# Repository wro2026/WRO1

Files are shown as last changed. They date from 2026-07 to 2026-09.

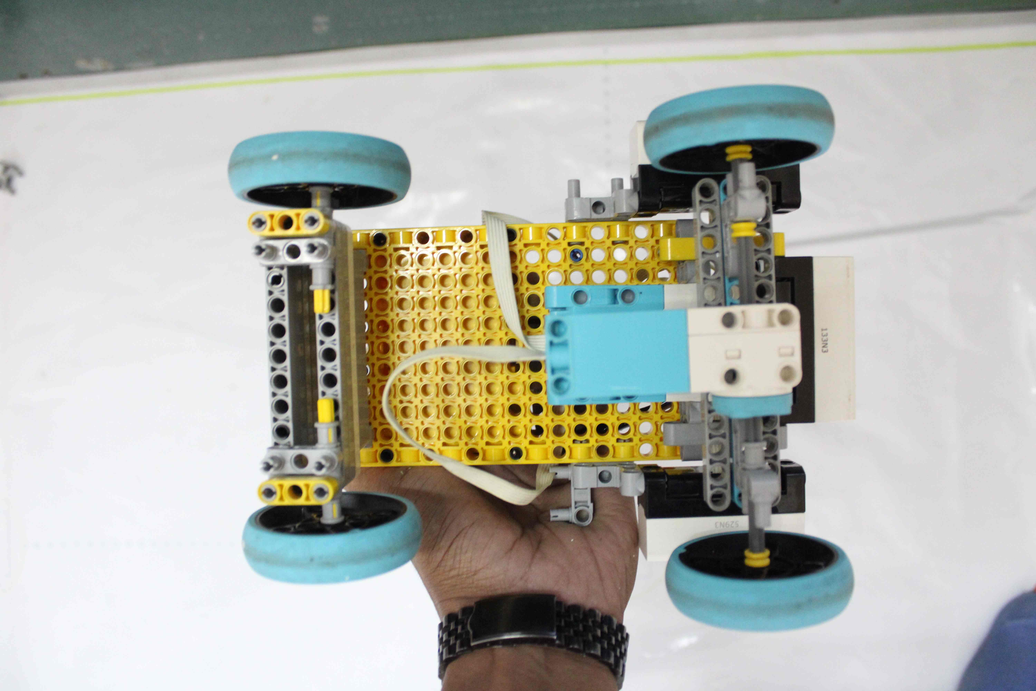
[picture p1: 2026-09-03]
Mechanical Design/Pictures/Pixabc.com_Compressed_to_500kb_IMG_7020.jpg

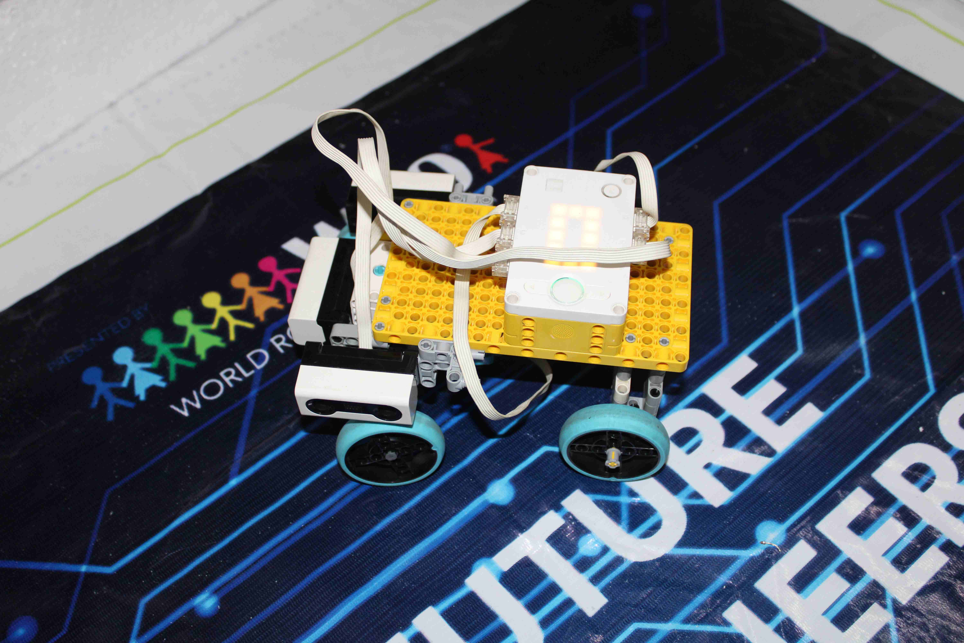
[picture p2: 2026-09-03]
Electronics/Pictures/Pixabc.com_Compressed_to_500kb_IMG_7013.jpg

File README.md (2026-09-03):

# WRO 2026 Future Engineers

This project is our WRO Future Engineers robot, developed with the goal of completing the competition challenge efficiently, reliably, and with as few accidents as possible. Our main target is to complete three laps within three minutes while maintaining accurate movement and avoiding unnecessary collisions. The robot has been developed through testing and several changes to both the hardware and software. The final version uses a LEGO SPIKE Prime Hub as the main controller, LEGO components for the mechanical structure, SPIKE Prime motors and sensors, a HuskyLens camera, and an ESP32 with a servo to allow the HuskyLens to communicate information to the SPIKE Prime system.

The robot has a LEGO-based chassis with approximate dimensions of 23 × 11 × 27 cm. The chassis is designed with a hollow structure to reduce unnecessary weight. LEGO was selected as the main construction material because it is easy to use, lightweight, stable, and simple to modify during development. This was particularly useful because the robot had to be changed and tested several times while we worked on improving its movement and turning performance. The LEGO structure also allowed us to make adjustments without having to rebuild the entire robot from the beginning.

The robot uses four wheels in total. The wheels have an approximate diameter of two inches, or about 5.08 cm. The SPIKE Prime Hub is positioned around the middle of the robot. This central placement helps keep the main controller within the body of the robot rather than placing it far toward one side. The drive system uses one small SPIKE Prime motor to drive the front two wheels. The drive system uses direct drive without gears. The steering system uses one large SPIKE Prime motor. The front two wheels are connected by a LEGO axle or bar, and the large motor rotates this bar so that the front wheels change direction. This provides the steering movement required by the robot.

The mechanical design was developed with simplicity in mind. Instead of using a complicated gear system, the drive motor is connected directly to the drive mechanism. This makes the system easier to understand and modify. The steering mechanism was also built using LEGO components so that the front wheels could be turned together. One of the main mechanical challenges during development was turning. Getting the robot to turn in a useful and repeatable way required testing and adjustment. The current version turns fairly well compared with the earlier versions, although turning was one of the main areas that required attention during development.

The chassis has remained stable during testing. We did not observe major problems with the structure bending, becoming loose, or coming apart during normal operation. We also did not identify a major tipping or leaning problem during our testing. These characteristics were important because the robot needs to remain stable while moving and turning. A stable structure makes it easier for the sensors to remain in their intended positions and allows the robot to behave more consistently during runs.

One of the most important decisions in the development of the robot was changing the platform used to control it. Our first version was built around a Raspberry Pi 4. This version was difficult and time-consuming to develop because we had to spend a lot of time working on the system and getting it to behave as required. Pairing and communication were also difficult during this stage. Because of these problems, we decided to change to the SPIKE Prime system. The second major version of the robot was therefore built using LEGO and SPIKE Prime. This change made the system easier for us to use and allowed us to make progress much more quickly. The move from the Raspberry Pi 4 version to the SPIKE Prime version was one of the biggest improvements made during the project.

The electronics system is controlled mainly by the LEGO SPIKE Prime Hub. The robot uses distance sensors, a SPIKE Prime color sensor, and a HuskyLens camera. There are distance sensors positioned around the robot, including one at the front and sensors on the sides. The front distance sensor is used to detect the environment in front of the robot, while the side distance sensors provide information about the robot's surroundings. These sensors are important for detecting distances and helping the robot make movement decisions.

The HuskyLens is mounted at the front of the robot and faces forward. It is used to detect colors. The color information is important because the robot uses it as part of its decision-making process. We originally used the SPIKE Prime color sensor by itself, but later added the HuskyLens because we found it to be more accurate for the color detection that we needed. This was an improvement to the sensing system because it gave us another way to identify the required color information.

The HuskyLens cannot directly communicate all of its information to the SPIKE Prime Hub in the way required by our system. To solve this problem, we use an ESP32 and a servo as an interface between the HuskyLens and the SPIKE Prime color sensor. The system works through the chain of HuskyLens to ESP32 to servo to SPIKE Prime color sensor and then to the SPIKE Prime Hub. The HuskyLens detects the color, the ESP32 processes the relevant information, and the servo is used to communicate the color change to the SPIKE Prime color sensor. The SPIKE Prime system can then use the color sensor information as part of its control process.

The SPIKE Prime Hub is powered using its rechargeable battery. The motors and sensors are connected to the SPIKE Prime Hub using the LEGO connection system. We did not make custom power wiring for the robot, and the main system does not use a separate external power supply. This keeps the electronics relatively simple and makes the system easier to assemble and modify.

We have not measured exact electrical values such as current consumption, total power consumption, or other detailed electrical measurements. These values are therefore not included as measured specifications of the robot. If we perform these measurements later, they can be added to the documentation. For the current version, the important point is that the robot uses the SPIKE Prime rechargeable battery as its main power source and the SPIKE Prime Hub as its main controller.

The software for the robot is written in Python. The program controls the motors, reads information from the sensors, and controls the robot's movement. The basic behavior is that the robot drives forward, detects when it needs to turn, performs the turn, and continues moving. The program also counts turns. After twelve turns, the robot is programmed to continue for approximately 30 cm and then stop. This provides a defined stopping behavior for the current program.

The robot normally drives at a fixed speed during normal movement. When it approaches a turn, the speed is reduced to help with the turning process. The steering system uses a fixed turning angle. The exact numerical value of the steering angle has not been measured and is therefore not listed as a specific number in this documentation. The turning behavior was adjusted through testing so that the robot could turn more effectively.

The distance sensors are used to detect distances around the robot. The front distance sensor helps detect what is ahead, while the side sensors provide additional information about the environment. The HuskyLens and SPIKE Prime color sensor provide color information that is used together with the distance information when the robot makes decisions. The robot therefore does not depend on only one sensor for its complete behavior. Instead, information from the available sensors is used to determine what action should be taken.

The general decision process used by the robot is based on detecting a situation, checking the available color information, deciding whether the robot should turn right or left, and then steering the robot. In a simplified form, the process can be described as detecting the situation, checking the color, deciding on the direction, and steering. The exact numerical sensor thresholds used by the final program have not been recorded in this documentation, so they are not stated as specific values.

When an unexpected sensor reading occurs, the program can retry the detection rather than immediately continuing with an incorrect decision. This gives the robot another opportunity to receive a usable sensor reading. This behavior is useful because sensor readings can sometimes not provide the expected information on the first attempt.

The algorithm was selected because it is straightforward and easier for us to program and understand. Our main priority was to create a system that could reliably complete the course rather than making the software unnecessarily complicated. The algorithm was developed through testing and tuning. During development, we tested different detection lengths for the distance sensors and changed values such as sensor thresholds, motor speed, and the steering angle. These changes were made based on how the robot behaved during testing.

Testing was an important part of the development process. Rather than assuming that the first design would work correctly, we tested the robot and used the results to make changes. Turning was one of the main areas that required testing because the robot needed to change direction accurately while maintaining its position and avoiding accidents. The distance sensor detection behavior was also tested by trying different detection lengths. Motor speed and steering settings were adjusted to find behavior that worked better on the course.

The project has gone through two major versions. The first version was developed using a Raspberry Pi 4. This version was difficult to develop because of the amount of work required to make the system behave correctly and because pairing was difficult. The second version moved to LEGO and SPIKE Prime. This change made development easier and allowed us to make progress more quickly. The switch to LEGO and SPIKE Prime was therefore one of the most significant changes made during the project.

The current robot combines a simple LEGO mechanical structure with a SPIKE Prime control system and additional sensing through HuskyLens and ESP32. The mechanical design focuses on keeping the robot lightweight, stable, and easy to modify. The electronics focus on using the SPIKE Prime Hub, distance sensors, the SPIKE color sensor, and the HuskyLens to provide the information needed for the robot's movement decisions. The software connects these components together and controls the robot according to the programmed behavior.

The project is designed around the goal of completing three laps within three minutes while minimizing accidents. Speed is therefore important, but reliability is also important. A robot that moves quickly but frequently makes incorrect turns or has accidents would not meet the project's goal as effectively as a robot that maintains a good balance between movement speed and accuracy. For this reason, testing and tuning focused on the interaction between sensor detection, motor speed, and turning behavior.

There are some specifications that have not yet been measured. We have not recorded an exact top speed, exact motor torque, exact steering angle, exact total robot weight, or detailed electrical power consumption. These values should not be treated as known specifications. If more detailed measurements are taken in future testing, they can be added to the repository to make the technical documentation more complete.

The current design has several strengths. The LEGO chassis is lightweight and easy to modify. The structure has remained stable during testing without major bending or loosening problems. The SPIKE Prime Hub provides a simpler development platform than the Raspberry Pi 4 system that we originally tried. The combination of distance sensors, the SPIKE Prime color sensor, and HuskyLens provides multiple sources of information for the robot. The software is also straightforward, making it easier to understand, test, and adjust.

At the same time, turning remains an important area of the robot's development. Although the current robot turns fairly well, turning was one of the biggest mechanical and programming challenges during development. Further testing could be used to improve the consistency of turns and to determine more accurate mechanical measurements such as the steering angle. Additional testing could also provide measured speed, weight, power consumption, and other useful technical information.

The development process demonstrates an iterative approach. We began with one hardware and control approach, identified problems, and then changed the system. We tested the new system, adjusted sensor and motor settings, and continued improving the robot. Instead of treating the original design as final, we used the results from testing to guide changes. This process helped us move from the Raspberry Pi 4 version to the SPIKE Prime version and improve the robot's overall usability.

The final system is intended to be understandable and reproducible from the information provided in this repository. The mechanical design, electronics, software, algorithms, testing, iterations, photos, and videos can be organized in separate folders so that each part of the project can be documented clearly. The documentation focuses on the actual robot and its development rather than including unnecessary material that does not contribute to understanding the project.

Overall, this project represents the development of a WRO Future Engineers robot from an initial Raspberry Pi 4 concept to a LEGO SPIKE Prime-based system. The robot uses a lightweight LEGO chassis, four wheels, a small drive motor, a large steering motor, distance sensors, a SPIKE Prime color sensor, a HuskyLens camera, an ESP32, and a servo interface. Its software is written in Python and uses sensor information to control movement, turning, and stopping behavior. Through testing and iteration, the robot was adjusted to improve its turning, sensor detection, motor behavior, and overall reliability.

The main lesson from the development process was the importance of testing and making changes based on actual robot behavior. The switch from Raspberry Pi 4 to SPIKE Prime significantly improved the development process for our team, while the addition of HuskyLens improved the color detection system. The current design provides a practical balance between mechanical simplicity, electronic functionality, and software control. The project will continue to be improved through further testing, especially in areas such as turning consistency and measured performance.

Our final objective remains to complete three laps within three minutes with the least number of accidents possible. Every part of the robot, from the lightweight LEGO chassis to the sensor system and Python program, contributes to this objective. The repository documents the development process and the current design so that the work completed by the team can be clearly understood and evaluated.

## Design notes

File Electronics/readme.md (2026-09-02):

2. Power & Sensor Architecture

2.1 System Architecture

The SPIKE Prime Hub is the main controller. It controls the drive and steering motors and processes information used for autonomous navigation. An ESP32 is also used as an interface because the SPIKE Prime system cannot directly interpret the HuskyLens camera.
The main information flow is:
Distance sensors → SPIKE Prime Hub → navigation decisions
HuskyLens → ESP32 → servo interface → SPIKE Prime color sensor → SPIKE Prime Hub
SPIKE Prime rechargeable battery → SPIKE Prime Hub → SPIKE Prime components

2.2 Power System

The robot is powered by the SPIKE Prime rechargeable battery. The SPIKE Prime motors and sensors use the Hub's normal connections. The ESP32 and servo form the additional HuskyLens interface.
The present documentation does not contain measured current values for each component, so unsupported current figures are not stated. For a complete final power budget, current should be measured for the drive motor, steering motor, Hub electronics, ESP32, servo and sensors under representative operating conditions.



2.3 Sensor Selection

The robot uses distance sensors, the SPIKE Prime color sensor and HuskyLens.
•	Distance sensors provide information about objects or walls around the robot.
•	The HuskyLens provides color information from the front of the robot.
•	The SPIKE Prime color sensor provides the input pathway through which the HuskyLens color information is communicated to the SPIKE system.
Initially, the robot relied on the SPIKE Prime color sensor. During development, the team found that HuskyLens gave more accurate color detection. Instead of abandoning SPIKE Prime, an ESP32 and servo interface was added. This preserved SPIKE Prime as the main controller while improving color detection.

2.4 Sensor Placement and Field Geometry

The distance sensors are positioned on the sides of the robot so that they can observe nearby walls or objects relative to the robot's lateral position. This information helps the robot determine when a navigation decision is required.
The HuskyLens is mounted at the front and faces forward because color information must be obtained from the area ahead of the robot. The SPIKE Prime color sensor is positioned so that the servo-operated interface can communicate the detected color change.
Placement is therefore linked to the geometry of the field: side sensors observe lateral boundaries, while the forward-facing camera observes information in the robot's path.

2.5 Calibration and Reliability

Sensor thresholds and detection distances are treated as adjustable parameters rather than permanent assumptions. During testing, different distance thresholds were tried to determine when the robot should respond to an object or field condition.
A practical calibration procedure is to collect repeated readings at known distances, identify a stable threshold that separates the required field condition from normal travel, and then repeat the test several times. The final threshold should be selected from the repeated test results.
For reliability, an unexpected or unstable sensor reading should not immediately trigger a turn. The software should repeat the detection/decision process and only continue when a valid condition is identified. This reduces the effect of a single noisy reading.

2.6 Electronics Design Change

The major electronics iteration was the addition of HuskyLens, ESP32 and servo. The original SPIKE color sensor was not sufficiently accurate for the team's color-detection requirement. HuskyLens improved detection, but it could not directly communicate with SPIKE Prime. The interface solved this compatibility constraint.
This demonstrates a subsystem trade-off: improving sensing accuracy increased electronics complexity. The team accepted the additional ESP32 and servo because the resulting detection system was more useful while SPIKE Prime could remain the main controller.

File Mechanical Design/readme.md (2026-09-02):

1. Mobility & Mechanical Design

1.1 Chassis Design

Our robot chassis is constructed entirely from LEGO components. The approximate overall dimensions are 23 cm × 11 cm × 27 cm. The chassis uses a hollow LEGO structure to reduce unnecessary mass while retaining the structural members needed to mount the motors, wheels, hub and sensors.
LEGO was selected because it allows rapid mechanical iteration. During development, parts can be repositioned without permanently modifying the structure. This was particularly important when we changed the steering geometry and sensor positions during testing.
The robot has four wheels with an approximate diameter of 2 inches (5.08 cm). The SPIKE Prime Hub is positioned approximately near the middle of the chassis. This keeps the main mass close to the center of the vehicle and provides a practical mounting arrangement for the drive and steering systems.

1.2 Drive System

The robot uses one SPIKE Prime small motor for propulsion. The motor is connected directly to the front two wheels without intermediate gearing. The front wheels are mechanically linked through an axle so that the drive motor transfers rotation to both wheels.
The direct-drive arrangement was selected because it has few mechanical parts, is easy to inspect, and is simple to modify. The robot can drive forwards and backwards.
The main trade-off is that direct drive provides less opportunity to change wheel speed or torque through gearing. We accepted this trade-off because the current competition objective prioritizes predictable movement and reliable turning over a complex drivetrain.

1.3 Steering System

One SPIKE Prime large motor controls steering. The two front wheels are connected by a LEGO steering bar. When the steering motor rotates the bar, both front wheels change direction together.
The steering motor is mechanically separate from the drive motor. Separating propulsion and steering makes the control system easier to tune because drive speed and steering angle can be adjusted independently.
Testing showed that the current steering arrangement can complete the required turns reliably. Steering performance was improved by adjusting the steering angle and reducing drive speed during turns.

1.4 Torque and Speed Reasoning

The drive-wheel diameter is approximately 5.08 cm, giving a wheel circumference of approximately 15.96 cm. The theoretical linear speed can therefore be estimated from wheel rotational speed using v = πdN/60, where d is wheel diameter in metres and N is wheel speed in revolutions per minute.
For example, once the actual motor output speed under load is measured, it can be converted directly into the robot's theoretical wheel speed. The measured ground speed should then be compared with the theoretical value because wheel slip, load and surface friction can reduce the actual speed.
Wheel torque is important because the robot must accelerate the chassis and overcome rolling resistance while turning. The effective tractive force can be related to wheel torque by F = T/r, where T is wheel torque and r is wheel radius. Because the exact loaded motor torque has not yet been measured, we do not claim an unsupported numerical torque value. Instead, the design uses direct drive and moderate speed to favor predictable motion.
For the final build, the recommended validation measurements are: time over a fixed 1 m distance, maximum repeatable speed, loaded wheel torque if measurement equipment is available, and turning radius. These measurements should be recorded on the final competition robot rather than estimated from unloaded motor specifications.

1.5 Mechanical Stability and Rigidity

The four-wheel configuration provides four contact points with the field. The hollow chassis reduces mass while retaining the LEGO members needed to support the motors, wheels and electronics.
During normal driving tests, the chassis remained assembled and no major bending or separation was observed. The steering assembly also remained mechanically connected while changing direction.
The main mechanical risks are loose LEGO connections, steering backlash, wheel slip and excessive speed during turns. These risks are reduced by checking connections before runs, using a consistent steering setting, slowing before turns, and testing the robot repeatedly on the competition surface.

1.6 Design Choices and Trade-offs

Decision	Alternative considered	Reason for final choice	Engineering trade-off
LEGO chassis	More permanent/custom chassis	Fast modification and iteration	Less rigid than some custom structures
SPIKE Prime drive	Raspberry Pi-based system	Simpler motor/control integration	Less software flexibility
Direct drive	Intermediate gearing	Fewer mechanical parts	Less ability to trade speed for torque
Separate steering motor	Single combined mechanism	Independent steering control	Requires an additional motor

A major system-level decision was changing from the original Raspberry Pi 4 approach to SPIKE Prime. The Raspberry Pi version was difficult and time-consuming because development included a learning-based system and pairing/setup problems. The SPIKE Prime version allowed the team to make mechanical and software changes more quickly. The final choice therefore prioritized reliable development and repeatable testing.

1.7 Design Iterations and Testing

Version 1: Raspberry Pi 4

The first version used a Raspberry Pi 4. The main difficulty was system complexity. Development of the learning approach required significant time, while pairing and setup also caused delays. The slow development cycle made mechanical iteration harder.

Version 2: LEGO SPIKE Prime

The second version changed to SPIKE Prime with a LEGO chassis. This reduced setup complexity and made mechanical changes faster. The current design uses four wheels, 2-inch wheels, one small drive motor, one large steering motor, direct drive and a LEGO steering bar.
Testing and tuning focused on steering angle, drive speed and detection behavior. The robot slows before turns because a lower speed reduces overshoot and makes the steering response more predictable.

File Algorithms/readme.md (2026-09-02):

4. Systems Thinking & Engineering Decisions

4.1 How the Subsystems Work Together

The robot is an integrated system rather than four independent parts. The mechanical system determines how quickly and accurately the robot can turn. The sensor architecture determines what information the software receives. The software converts sensor information into navigation decisions. Those decisions command the mechanical drive and steering system.
The main interaction chain is:
Field condition → sensors → ESP32/HuskyLens interface where required → SPIKE Hub → navigation decision → motor speed/steering → robot movement → new sensor readings
A change in one subsystem therefore affects the others. For example, increasing speed may improve straight-line travel time but can make turning less accurate. Similarly, moving a sensor changes the distance at which the software must react.

4.2 Engineering Constraints

•	The robot must operate autonomously.
•	The robot must complete 3 laps within the 3-minute objective.
•	The chassis must remain mechanically stable during repeated driving.
•	Steering must be controllable independently from propulsion.
•	Sensor information must be available in time for a turn decision.
•	HuskyLens must be integrated despite the SPIKE Prime compatibility limitation.
•	The design must remain practical to build and modify with the available LEGO system.

4.3 Major Engineering Decisions

Problem	Options	Decision	Reasoning
Main control platform	Raspberry Pi 4 or SPIKE Prime	SPIKE Prime	Reduced setup complexity and allowed faster development
Color detection	SPIKE color sensor only or HuskyLens	HuskyLens + ESP32 + servo interface	Improved color detection while retaining SPIKE as main controller
Drive transmission	Direct drive or gearing	Direct drive	Simple, compact and easy to modify
Steering	Single mechanical steering system or separate control	Separate large motor	Allows independent steering control
Navigation	Complex learning-based approach or simpler sensor logic	Sensor-based logic	Easier to test, tune and understand for the current task

4.4 Iteration Cycle

The development process followed an iterative engineering cycle:
Build → Test → Identify limitation → Change design → Retest → Select the better-performing configuration
Iteration 1 changed the main platform from Raspberry Pi 4 to SPIKE Prime because the first approach was too complex and slow to develop.
Iteration 2 changed the color-detection architecture by adding HuskyLens, ESP32 and a servo because the original color-sensing approach was less accurate.
Further tuning changed detection distances, motor speed and steering angle based on observed robot behavior.

4.5 Risk and Failure Analysis

Risk / failure point	Possible effect	Mitigation	Validation
Incorrect distance reading	Turn triggered too early/late	Use calibrated thresholds and repeat unstable detections	Repeated sensor tests
Color detection error	Wrong left/right decision	Use HuskyLens and validate color information	Repeated color tests
High speed during turn	Overshoot or missed path	Slow before turning	Compare turn behavior at different speeds
Steering backlash	Inconsistent turn angle	Use a fixed steering setting and check mechanical connections	Repeated turning tests
Wheel slip	Actual path differs from expected path	Use controlled speed and observe wheel/field interaction	Repeated distance/turn tests
Loose chassis connection	Mechanical instability	Inspect and reinforce critical LEGO connections	Repeated driving tests
Interface failure	HuskyLens information unavailable to SPIKE	Keep SPIKE color sensor as the communication pathway and retry detection	Integration tests

4.6 Testing Metrics

To make engineering decisions measurable, the final testing record should use repeatable metrics rather than subjective descriptions alone.



4.7 Performance Objective

The algorithm's main objective is to complete 3 laps within 3 minutes while minimizing accidents. Therefore, the engineering goal is not simply maximum speed. The selected design balances speed, sensing reliability, steering control and mechanical stability.
The final configuration should be selected from repeated tests. If a higher speed reduces lap time but increases missed turns or accidents, the lower and more reliable speed is the better engineering choice for the competition objective.

4.8 Final Engineering Rationale

The final robot was developed by progressively reducing unnecessary complexity while improving the parts that directly affect autonomous performance. SPIKE Prime was selected as the main control platform because it accelerated development. Direct drive and LEGO construction were retained because they are simple and easy to modify. HuskyLens was added because improved color detection was valuable, while the ESP32 and servo interface solved the compatibility constraint.
The resulting architecture connects mechanical, electronic and software decisions: sensor placement determines when the software can detect a condition; detection thresholds determine when the robot begins a maneuver; motor speed and steering angle determine the physical result; and repeated testing is used to tune these parameters. This systems approach is intended to produce a robot that is not only functional, but also understandable, testable and reproducible.

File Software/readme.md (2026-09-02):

3. Software Architecture & Obstacle Strategy

3.1 Programming Architecture

The robot is programmed in Python. The software coordinates motor control, sensor input, steering and autonomous navigation.
The software can be understood as five functional stages: sensing, validation, decision, motion control and route completion.



3.2 Main Autonomous State Machine

The robot follows the following state sequence:

1.	START: initialize the controller, motors, sensors and required variables.

2.	DRIVE: move forward at the normal driving speed.

3.	DETECT: monitor the distance sensors for a navigation condition.

4.	VALIDATE: confirm the detection and check the relevant color information.

5.	DECIDE: determine whether the required direction is left or right.

6.	SLOW: reduce drive speed before the turn.

7.	TURN: move the steering motor to the selected steering angle.

8.	COUNT: increment the completed-turn counter.

9.	CONTINUE: return to forward driving.

10.	STOP: after 12 turns, drive approximately 30 cm and stop.

The state-machine structure was selected because it separates sensing, decision-making and movement. This makes the behavior easier to test and tune than a single long sequence of motor commands.

3.3 Turn Decision Algorithm

The decision process is:
Detect condition → Check color → Decide left/right → Steer → Continue
The robot does not use one fixed direction for every turn. Instead, the relevant sensor condition and color information are considered before the steering direction is selected.
Conceptually, the control logic is:
IF a turn condition is detected: validate the reading; check color; select LEFT or RIGHT; reduce speed; apply the steering angle; complete the turn; count the turn; return to driving.

3.4 Obstacle Strategy and Edge Cases

Distance sensors provide information about objects or walls. If an object is detected, the robot checks the color information before selecting a path. The selected direction is then passed to the steering system.
•	If the sensor reading is unexpected or unstable, repeat the detection/decision process rather than immediately making a turn.
•	If a valid condition is detected but the color information does not provide the expected classification, the software should repeat the sensing step before committing to a direction.
•	During turns, the robot reduces drive speed to reduce overshoot.
•	After each successful turn, the turn counter is updated so the route can be completed without a manual stop.

3.5 Steering Control

The large SPIKE Prime motor controls the front-wheel steering mechanism. A predetermined steering angle is used for turns. This angle was adjusted during testing to obtain reliable turning behavior.
The robot normally drives at a fixed speed and uses a lower speed during turns. This creates a simple two-speed strategy: efficient forward travel and controlled turning.

3.6 Turn Counting and Stopping

The current route-control sequence is designed to complete 12 turns. Once the counter reaches 12, the robot continues for approximately 30 cm and then stops.
This stopping strategy reduces dependence on a manual operator and gives the autonomous run a defined end condition.

3.7 Software Testing and Tuning

The main software parameters tuned during development were sensor thresholds, detection distance, motor speed and steering angle. These parameters were changed after observing robot behavior during testing.



The final report should retain the measured values from the team's actual tests. Values should not be invented merely to make the documentation appear complete.

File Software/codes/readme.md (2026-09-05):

# =============================================================================
# Pybricks (SPIKE Prime / Inventor Hub)
# WRO Obstacle Challenge — NO parallel parking
# -----------------------------------------------------------------------------
# Merge of:
#   * WRO Open Challenge corridor driver (90 deg gyro arcs at openings)
#   * HuskyLens color dodges (GREEN = LEFT, RED = RIGHT)
#
# PORT MAP
#     A = drive motor (rear, with encoder)
#     B = steering motor (front wheels)
#     C = distance sensor LEFT
#     D = distance sensor FRONT
#     E = distance sensor RIGHT
#     F = HuskyLens UART, Color Recognition, 9600 baud
#
# Teach the HuskyLens:
#     Color ID 1 = GREEN pillar  -> pass on the LEFT
#     Color ID 2 = RED   pillar  -> pass on the RIGHT
#
# WHAT THE CAR DOES
#     CRUISE     wall-center + IMU heading hold, watch for openings AND colors
#     COLOR      GREEN: 35 deg LEFT while the pillar is visible, then hold
#                50 deg RIGHT for 30 cm, straighten the wheels, then go
#                20 cm straight. RED is the mirror: 35 deg RIGHT, then
#                50 deg LEFT for 30 cm, straighten, 20 cm straight.
#                Corridor heading is KEPT (gyro is not zeroed) so the next
#                90 deg corner still lines up. Wall-centering is boosted
#                briefly so the car returns to the middle of the lane.
#     APPROACH   opening seen; hold heading until the front wall is close
#     TURN       closed-loop 90 deg gyro arc (never stops mid-run)
#     POST       short gyro-straight, then back to CRUISE
#     FINAL      after MAX_TURNS (12 = 3 laps of 4 corners), center for
#                FINAL_DRIVE_MM and stop. No parking.
#
# The car is not allowed to stop until every 90 deg turn is done.
# A corner turn is ONLY started when a real opening is detected (the open
# side reads farther than OPEN_DISTANCE_MM = 1000 mm) AND the front wall
# has been reached. A front wall alone -- e.g. a color block that the
# HuskyLens has not identified yet -- NEVER triggers a turn; the car just
# slows down and lets the color dodge handle it.
#
# STARTUP
#     1. Point the car straight down the corridor.
#     2. Physically straighten the front wheels.
#     3. Press Run. That heading becomes 0.
# =============================================================================

from pybricks.hubs import PrimeHub
from pybricks.pupdevices import Motor, UltrasonicSensor
from pybricks.parameters import Port, Stop, Icon, Color
from pybricks.tools import wait, StopWatch
from pybricks.iodevices import UARTDevice

# ------------------------- PORTS -------------------------
hub = PrimeHub()
drive = Motor(Port.A)
steer = Motor(Port.B)
left_sensor = UltrasonicSensor(Port.C)
front_sensor = UltrasonicSensor(Port.D)
right_sensor = UltrasonicSensor(Port.E)

# --------------------- DRIVE SETTINGS -------------------
# Regulated rear-motor speed, deg/s. Negative if the car drives backward.
DRIVE_SPEED = -500
TURN_SPEED = -280           # slower in the 90 deg arc (same SIGN as DRIVE)
STEERING_SPEED = 400       # deg/s of the steering servo

# Steering MOTOR angle, not the road-wheel angle.
MAX_STEERING_DEG = 32
MAX_TURN_STEERING_DEG = 40          # also the hard clamp for dodges/recovery
# STEERING_SIGN: +1 if a POSITIVE motor angle turns the car LEFT
# (same meaning as the working SPIKE 3 program). Flip to -1 if reversed.
STEERING_SIGN = 1
# YAW_SIGN: used after converting Pybricks heading (clockwise +)
# into a left-positive yaw like the SPIKE 3 program. Flip if turns go
# the wrong way.
YAW_SIGN = 1

# ---------------------- STOP SETTINGS -------------------
# Front-wall stopping is ONLY used in FINAL, after all MAX_TURNS are done.
STOP_DISTANCE_MM = 180
FRONT_CONFIRMATIONS = 2
FRONT_STOP_MAX_YAW_DEG = 12
EMERGENCY_STOP_DISTANCE_MM = 10

# ------------------- CRUISE CONTROLLER GAINS ------------
WALL_KP = 0.11
WALL_DEADBAND_MM = 8
WALL_FILTER_AMOUNT = 0.25
HEADING_KP = 1.20
YAW_DAMPING = 1.80

# After a color dodge, wall-centering is stronger for this long so the
# car hunts the middle of the lane instead of staying offset.
RECENTER_MS = 3000
RECENTER_WALL_KP = 0.20
RECENTER_DEADBAND_MM = 4

# ------------------- TURN DETECTION ---------------------
SPIKE_JUMP_MM = 500
SPIKE_CONFIRMATIONS = 4
BASELINE_FILTER_AMOUNT = 0.12
MAX_WALL_DISTANCE_MM = 2000
# An opening ONLY counts when the open side reads FARTHER than this.
# The GREEN/RED color blocks stand INSIDE the corridor, so the side
# sensors never read > 1000 mm for them -- a block can never look like
# an opening, and a front wall without a real opening never triggers a
# turn (the HuskyLens color dodge handles blocks instead).
OPEN_DISTANCE_MM = 1000

# ------------------- TURN EXECUTION ---------------------
TURN_AT_FRONT_DISTANCE_MM = 900
FRONT_CLOSE_CONFIRMATIONS = 1
WALL_RETURN_CONFIRMATIONS = 2
WALL_RETURN_MARGIN_MM = 150     # side wall counts as "back" if within baseline + this
MAX_APPROACH_DISTANCE_MM = 700
POST_TURN_DRIVE_MM = 100
ODOMETER_MM_PER_MOTOR_DEG = 0.49    # ~56 mm wheel; pi*56/360

TURN_ANGLE_DEG = 90
TURN_KP = 2.0
TURN_DONE_TOLERANCE_DEG = 6
TURN_TIMEOUT_MS = 6000

MAX_TURNS = 12                      # 3 laps x 4 corners
FINAL_DRIVE_MM = 300                # settle between walls, then stop

# When something is straight ahead but NO opening was detected, never turn:
# it is almost certainly a color block the HuskyLens has not identified yet.
# Slow down so the camera has time to see the color, and the color dodge
# takes over from there.
BLOCK_AHEAD_SLOWDOWN_MM = 500
BLOCK_AHEAD_SPEED = -200

# ------------------- COLOR (HuskyLens) ------------------
#  GREEN  -> pass on the LEFT   (dodge LEFT, recover RIGHT)
#  RED    -> pass on the RIGHT  (dodge RIGHT, recover LEFT)
#  Logical steering convention here: + = wheels RIGHT, - = wheels LEFT.
GREEN_ID = 1                        # color ID of the GREEN pillar
RED_ID = 2                          # color ID of the RED pillar
GREEN_STEER = -35                   # -35 logical  = LEFT dodge
GREEN_RECOVER = 50                  # +50 logical  = RIGHT recovery
RED_STEER = 35                      # +35 logical  = RIGHT dodge
RED_RECOVER = -50                   # -50 logical  = LEFT recovery
COLOR_RECOVER_MM = 300              # 30 cm HOLDING the recovery angle
RECOVER_STRAIGHT_MM = 200           # 20 cm straight after straightening
COLOR_LOST_CONFIRM_MS = 300

HUSKY_PORT = Port.F
HUSKY_BAUD = 9600
HUSKY_POWER_PIN = 0                 # 2 if the camera needs hub pin power
HUSKY_TIMEOUT_MS = 60

LOOP_TIME_MS = 50
PRINT_DEBUG = False

# ------------------------ MODES -------------------------
MODE_CRUISE = 0
MODE_APPROACH = 1
MODE_TURN = 2
MODE_POST = 3
MODE_FINAL = 4
MODE_NAMES = ("CRUISE", "APPROACH", "TURN", "POST", "FINAL")

# ------------------------------------------------------------------ helpers
def clamp(value, low, high):
    if value < low:
        return low
    if value > high:
        return high
    return value

def distance_is_valid(value):
    return value is not None and value > 0

def read_mm(sensor):
    """Pybricks returns 2000 mm when nothing is seen; map that to -1."""
    try:
        d = sensor.distance()
    except OSError:
        return -1
    if d is None or d <= 0 or d >= 2000:
        return -1
    return d

def angle_difference(new_angle, old_angle):
    difference = new_angle - old_angle
    while difference > 180:
        difference -= 360
    while difference < -180:
        difference += 360
    return difference

def wrap_angle(angle):
    while angle > 180:
        angle -= 360
    while angle <= -180:
        angle += 360
    return angle

def yaw_left_positive():
    """
    Pybricks hub.imu.heading() is clockwise-positive (RIGHT).
    The Open Challenge controller is left-positive. Convert here so the
    rest of the math matches the working SPIKE 3 program.
    """
    return wrap_angle(YAW_SIGN * (-hub.imu.heading()))

def traveled_mm(start_position):
    return abs(drive.angle() - start_position) * ODOMETER_MM_PER_MOTOR_DEG

def update_side_reading(reading_mm, baseline, open_count, open_threshold_mm):
    """
    Wall tracking for one side. An 'open' count only builds up when the
    side truly opens up: the reading jumps away from the wall baseline AND
    is farther than open_threshold_mm (1000 mm). A missing reading means
    no wall within 2 m -- that is open too. Wall-like readings (a color
    block in the corridor) always stay below the threshold and never count.
    """
    if distance_is_valid(reading_mm):
        if baseline is None:
            if reading_mm <= MAX_WALL_DISTANCE_MM:
                baseline = reading_mm
            return baseline, 0
        if (
            reading_mm > baseline + SPIKE_JUMP_MM
            and reading_mm > open_threshold_mm
        ):
            return baseline, open_count + 1
        baseline = baseline + (reading_mm - baseline) * BASELINE_FILTER_AMOUNT
        return baseline, 0
    if baseline is not None:
        return baseline, open_count + 1
    return baseline, 0

def u16le(data, index):
    return data[index] | (data[index + 1] << 8)

# ------------------------------------------------------------------ motors
def start_drive(speed=None):
    drive.run(DRIVE_SPEED if speed is None else speed)

def stop_drive():
    drive.brake()

def apply_steering(conceptual_left_deg, last_target, limit=None):
    """
    conceptual_left_deg: + = turn LEFT (SPIKE 3 convention).
    STEERING_SIGN maps that onto the motor.
    """
    if limit is None:
        limit = MAX_TURN_STEERING_DEG
    target = int(STEERING_SIGN * conceptual_left_deg)
    target = clamp(target, -limit, limit)
    if target != last_target:
        steer.run_target(STEERING_SPEED, target, then=Stop.HOLD, wait=False)
    return target

def steer_logical(logical_right_deg, wait_done=True):
    """logical_right_deg: + = wheels RIGHT, - = wheels LEFT."""
    # conceptual_left = -logical_right, then STEERING_SIGN
    motor_angle = STEERING_SIGN * (-logical_right_deg)
    motor_angle = clamp(motor_angle, -MAX_TURN_STEERING_DEG, MAX_TURN_STEERING_DEG)
    steer.run_target(STEERING_SPEED, motor_angle, then=Stop.HOLD, wait=wait_done)

# ------------------------------------------------------------------ HuskyLens
CMD_KNOCK = bytes((0x55, 0xAA, 0x11, 0x00, 0x2C, 0x3C))
CMD_BLOCKS_LEARNED = bytes((0x55, 0xAA, 0x11, 0x00, 0x24, 0x34))
CMD_OK = 0x2E
CMD_INFO = 0x29
CMD_BLOCK = 0x2A

def _checksum(payload):
    s = 0
    for b in payload:
        s += b
    return s & 0xFF

def cmd_blocks_by_id(color_id):
    frame = bytearray((0x55, 0xAA, 0x11, 0x02, 0x27, color_id & 0xFF, 0x00))
    frame.append(_checksum(frame))
    return bytes(frame)

class HuskyLens:
    def __init__(self, port, baudrate=9600, power_pin=0):
        kwargs = {"baudrate": baudrate, "timeout": 200}
        if power_pin:
            kwargs["power_pin"] = power_pin
        self.uart = UARTDevice(port, **kwargs)
        wait(300)
        self.uart.clear()

    def _read_exact(self, n, timeout_ms):
        watch = StopWatch()
        data = b""
        while len(data) < n and watch.time() < timeout_ms:
            waiting = self.uart.waiting()
            if waiting:
                take = min(waiting, n - len(data))
                data += self.uart.read(take)
            else:
                wait(1)
        return data

    def _read_packet(self, timeout_ms):
        watch = StopWatch()
        while watch.time() < timeout_ms:
            hdr = self._read_exact(2, max(5, timeout_ms - watch.time()))
            if len(hdr) < 2:
                return None, b""
            if hdr[0] == 0x55 and hdr[1] == 0xAA:
                rest = self._read_exact(3, 40)
                if len(rest) < 3:
                    return None, b""
                address, length, cmd = rest[0], rest[1], rest[2]
                if address != 0x11:
                    continue
                payload = self._read_exact(length + 1, 40)
                if len(payload) < length + 1:
                    return None, b""
                return cmd, payload[:length]
            if hdr[1] == 0x55:
                extra = self._read_exact(1, 10)
                if extra == b"\xAA":
                    rest = self._read_exact(3, 40)
                    if len(rest) == 3 and rest[0] == 0x11:
                        length, cmd = rest[1], rest[2]
                        payload = self._read_exact(length + 1, 40)
                        if len(payload) >= length + 1:
                            return cmd, payload[:length]
        return None, b""

    def knock(self):
        try:
            self.uart.clear()
            self.uart.write(CMD_KNOCK)
            cmd, _ = self._read_packet(150)
            return cmd == CMD_OK
        except OSError:
            return False

    def seen_ids(self, wanted=(1, 2)):
        found = set()
        try:
            self.uart.clear()
            self.uart.write(CMD_BLOCKS_LEARNED)
            cmd, payload = self._read_packet(HUSKY_TIMEOUT_MS)
            if cmd != CMD_INFO or len(payload) < 2:
                return self._seen_by_id(wanted)
            n = u16le(payload, 0)
            for _ in range(n):
                bcmd, bpay = self._read_packet(40)
                if bcmd != CMD_BLOCK or len(bpay) < 10:
                    break
                block_id = u16le(bpay, 8)
                if block_id in wanted:
                    found.add(block_id)
            return found
        except OSError:
            return found

    def _seen_by_id(self, wanted):
        found = set()
        for color_id in wanted:
            try:
                self.uart.clear()
                self.uart.write(cmd_blocks_by_id(color_id))
                cmd, payload = self._read_packet(HUSKY_TIMEOUT_MS)
                if cmd == CMD_INFO and len(payload) >= 2 and u16le(payload, 0) > 0:
                    found.add(color_id)
                    self._read_packet(40)
            except OSError:
                pass
        return found

# ------------------------------------------------------------------ color dodge
def drive_while_color_visible(husky, color_id, logical_steer):
    """Hold 45 deg and keep driving until that color has been gone a moment."""
    steer_logical(logical_steer, wait_done=False)
    start_drive()
    lost = StopWatch()
    while True:
        steer_logical(logical_steer, wait_done=False)
        start_drive()
        if color_id in husky.seen_ids((color_id,)):
            lost.reset()
        elif lost.time() >= COLOR_LOST_CONFIRM_MS:
            break
        wait(10)

def drive_mm_while_steering(distance_mm, steer_start, steer_end):
    """Drive distance_mm, slewing steering from start to end. Keep rolling.
    Pass steer_start == steer_end to HOLD a constant angle for the distance."""
    target_motor = distance_mm / ODOMETER_MM_PER_MOTOR_DEG
    if target_motor < 1:
        return
    start_ang = drive.angle()
    steer_logical(steer_start, wait_done=True)
    start_drive()
    last_logical = None
    while abs(drive.angle() - start_ang) < target_motor:
        travelled = abs(drive.angle() - start_ang)
        progress = travelled / target_motor
        if progress > 1:
            progress = 1
        logical = steer_start + (steer_end - steer_start) * progress
        if logical != last_logical:
            steer_logical(logical, wait_done=False)
            last_logical = logical
        wait(10)

def color_dodge(husky, color_id, first_steer, recover_steer):
    """Dodge at first_steer while the color is visible, then recover.
       GREEN: first_steer=-35 (LEFT),  recover_steer=+50 (RIGHT)
       RED:   first_steer=+35 (RIGHT), recover_steer=-50 (LEFT)
       Sequence: hold the recovery angle for COLOR_RECOVER_MM (30 cm),
       straighten the wheels, then drive RECOVER_STRAIGHT_MM (20 cm)
       straight. The car never stops."""
    drive_while_color_visible(husky, color_id, first_steer)
    drive_mm_while_steering(COLOR_RECOVER_MM, recover_steer, recover_steer)
    steer_logical(0, wait_done=True)            # straighten tires, keep rolling
    drive_mm_while_steering(RECOVER_STRAIGHT_MM, 0, 0)
    start_drive()

# ------------------------------------------------------------------ main run
def drive_course(husky, connected):
    """
    One full attempt. Returns only after MAX_TURNS + FINAL_DRIVE_MM
    (or a FINAL-phase front wall). Never returns mid-run.
    """
    reference_yaw = yaw_left_positive()
    corridor_yaw = reference_yaw          # current corridor heading (kept, never zeroed)

    filtered_wall_error = 0.0
    previous_yaw_deg = reference_yaw
    last_steering_target = 0
    close_front_count = 0

    baseline_left = None
    baseline_right = None
    open_count_left = 0
    open_count_right = 0

    mode = MODE_CRUISE
    turn_direction = 0
    turn_target_yaw = reference_yaw
    turn_watch = StopWatch()
    phase_start_position = drive.angle()
    turn_side_baseline = None
    front_close_count = 0
    wall_return_count = 0
    turns_completed = 0

    green_latched = False
    red_latched = False
    clock = StopWatch()
    recenter_until = 0

    print("Reference yaw: %.1f deg" % reference_yaw)
    start_drive()

    while True:
        loop_watch = StopWatch()

        yaw_deg = yaw_left_positive()
        yaw_change = angle_difference(yaw_deg, previous_yaw_deg)
        previous_yaw_deg = yaw_deg
        heading_error = angle_difference(yaw_deg, corridor_yaw)

        front_mm = read_mm(front_sensor)
        left_mm = read_mm(left_sensor)
        right_mm = read_mm(right_sensor)

        all_turns_done = turns_completed >= MAX_TURNS

        # ---- FINAL-only stop (cannot fire before all 90 deg turns) ----
        if mode == MODE_FINAL and all_turns_done:
            emergency_stop = (
                distance_is_valid(front_mm)
                and front_mm <= EMERGENCY_STOP_DISTANCE_MM
            )
            normal_front_wall = (
                distance_is_valid(front_mm)
                and front_mm <= STOP_DISTANCE_MM
                and abs(heading_error) <= FRONT_STOP_MAX_YAW_DEG
            )
            if normal_front_wall:
                close_front_count += 1
            else:
                close_front_count = 0
            if emergency_stop or close_front_count >= FRONT_CONFIRMATIONS:
                stop_drive()
                steer_logical(0, wait_done=True)
                print("Final approach front wall - stopping")
                return
        else:
            close_front_count = 0

        # ---- GREEN / RED pillars (CRUISE only) ----
        # Do this BEFORE opening detection so a pillar is never mistaken
        # for a corner. Corridor heading (corridor_yaw) is kept.
        if mode == MODE_CRUISE and connected:
            seen = husky.seen_ids((GREEN_ID, RED_ID))
            if PRINT_DEBUG and seen:
                print("COLORS seen:", sorted(seen))

            # GREEN -> dodge LEFT (logical -35), recover RIGHT (+50)
            if GREEN_ID in seen and not green_latched:
                green_latched = True
                print("GREEN - pass on the LEFT")
                hub.light.on(Color.GREEN)
                hub.display.icon(Icon.ARROW_LEFT)
                color_dodge(husky, GREEN_ID, GREEN_STEER, GREEN_RECOVER)
                baseline_left = None
                baseline_right = None
                open_count_left = 0
                open_count_right = 0
                filtered_wall_error = 0.0
                last_steering_target = 0
                previous_yaw_deg = yaw_left_positive()
                recenter_until = clock.time() + RECENTER_MS
                hub.light.on(Color.WHITE)
                hub.display.icon(Icon.TRUE)
                start_drive()
                continue

            if GREEN_ID not in seen:
                green_latched = False

            # RED -> dodge RIGHT (logical +35), recover LEFT (-50)
            if RED_ID in seen and not red_latched:
                red_latched = True
                print("RED - pass on the RIGHT")
                hub.light.on(Color.RED)
                hub.display.icon(Icon.ARROW_RIGHT)
                color_dodge(husky, RED_ID, RED_STEER, RED_RECOVER)
                baseline_left = None
                baseline_right = None
                open_count_left = 0
                open_count_right = 0
                filtered_wall_error = 0.0
                last_steering_target = 0
                previous_yaw_deg = yaw_left_positive()
                recenter_until = clock.time() + RECENTER_MS
                hub.light.on(Color.WHITE)
                hub.display.icon(Icon.TRUE)
                start_drive()
                continue

            if RED_ID not in seen:
                red_latched = False

        # ---- opening detection (CRUISE) ----
        if mode == MODE_CRUISE:
            baseline_left, open_count_left = update_side_reading(
                left_mm, baseline_left, open_count_left, OPEN_DISTANCE_MM
            )
            baseline_right, open_count_right = update_side_reading(
                right_mm, baseline_right, open_count_right, OPEN_DISTANCE_MM
            )

            left_triggered = open_count_left >= SPIKE_CONFIRMATIONS
            right_triggered = open_count_right >= SPIKE_CONFIRMATIONS

            if left_triggered or right_triggered:
                if left_triggered and (
                    not right_triggered or open_count_left >= open_count_right
                ):
                    turn_direction = 1
                    turn_side_baseline = baseline_left
                    print("Opening on the LEFT - waiting for front wall")
                else:
                    turn_direction = -1
                    turn_side_baseline = baseline_right
                    print("Opening on the RIGHT - waiting for front wall")
                front_close_count = 0
                wall_return_count = 0
                mode = MODE_APPROACH
                phase_start_position = drive.angle()

        # ---- APPROACH: hold heading until the arc should start ----
        if mode == MODE_APPROACH:
            opening_side_mm = left_mm if turn_direction > 0 else right_mm

            # If the "opening" wall closes up again, it was a false spike:
            # cancel the turn and re-detect from CRUISE.
            wall_back = (
                distance_is_valid(opening_side_mm)
                and turn_side_baseline is not None
                and opening_side_mm <= turn_side_baseline + WALL_RETURN_MARGIN_MM
            )
            if wall_back:
                wall_return_count += 1
            else:
                wall_return_count = 0
            if (
                wall_return_count >= WALL_RETURN_CONFIRMATIONS
                and (
                    not distance_is_valid(front_mm)
                    or front_mm > TURN_AT_FRONT_DISTANCE_MM + SPIKE_JUMP_MM
                )
            ):
                print("Opening closed again - back to CRUISE")
                mode = MODE_CRUISE
                baseline_left = None
                baseline_right = None
                open_count_left = 0
                open_count_right = 0
                continue

            start_turn = False

            if (
                distance_is_valid(front_mm)
                and front_mm <= TURN_AT_FRONT_DISTANCE_MM
            ):
                front_close_count += 1
            else:
                front_close_count = 0
            if front_close_count >= FRONT_CLOSE_CONFIRMATIONS:
                start_turn = True
            elif traveled_mm(phase_start_position) >= MAX_APPROACH_DISTANCE_MM:
                # Opening detected but the front wall never came close enough;
                # turn into the opening anyway rather than plowing ahead.
                print("Approach distance timeout - turning into the opening")
                start_turn = True

            if start_turn:
                turn_target_yaw = wrap_angle(
                    corridor_yaw + turn_direction * TURN_ANGLE_DEG
                )
                turn_watch.reset()
                mode = MODE_TURN
                print(
                    "TURN %s to %.1f deg"
                    % ("LEFT" if turn_direction > 0 else "RIGHT", turn_target_yaw)
                )
                hub.display.icon(
                    Icon.ARROW_LEFT if turn_direction > 0 else Icon.ARROW_RIGHT
                )
                continue

        # ---- TURN: closed-loop 90 deg gyro arc (never stops mid-run) ----
        if mode == MODE_TURN:
            turn_error = angle_difference(turn_target_yaw, yaw_deg)
            steer_cmd_turn = clamp(
                TURN_KP * turn_error,
                -MAX_TURN_STEERING_DEG,
                MAX_TURN_STEERING_DEG,
            )
            last_steering_target = apply_steering(
                steer_cmd_turn, last_steering_target, MAX_TURN_STEERING_DEG
            )
            start_drive(TURN_SPEED)

            if abs(turn_error) <= TURN_DONE_TOLERANCE_DEG:
                corridor_yaw = turn_target_yaw
                mode = MODE_POST
                phase_start_position = drive.angle()
                print("Turn done -> POST")
                continue
            if turn_watch.time() >= TURN_TIMEOUT_MS:
                corridor_yaw = turn_target_yaw
                mode = MODE_POST
                phase_start_position = drive.angle()
                print("TURN TIMEOUT - forcing POST")
                continue

        # ---- POST: short gyro-straight, then back to CRUISE ----
        if mode == MODE_POST:
            if traveled_mm(phase_start_position) >= POST_TURN_DRIVE_MM:
                turns_completed += 1
                print(
                    "Turns completed: %d / %d"
                    % (turns_completed, MAX_TURNS)
                )
                baseline_left = None
                baseline_right = None
                open_count_left = 0
                open_count_right = 0
                filtered_wall_error = 0.0
                recenter_until = clock.time() + RECENTER_MS
                if turns_completed >= MAX_TURNS:
                    mode = MODE_FINAL
                    phase_start_position = drive.angle()
                    print("FINAL: all turns done - driving to the finish")
                    hub.display.icon(Icon.TRUE)
                    continue
                mode = MODE_CRUISE
                print("Back to CRUISE")
                continue

        # ---- FINAL: settle for FINAL_DRIVE_MM, then stop ----
        if mode == MODE_FINAL:
            if traveled_mm(phase_start_position) >= FINAL_DRIVE_MM:
                stop_drive()
                steer_logical(0, wait_done=True)
                print("Course complete - stopping")
                hub.display.icon(Icon.TRUE)
                return

        # ---- steering controller + drive ----
        # IMPORTANT: this whole block is SKIPPED during MODE_TURN. The TURN
        # block above already commands the steering and the drive speed, and
        # it runs later in the loop -- if this block ran too it would
        # OVERRIDE the turn command every cycle (the cruise controller is
        # clamped to 32 deg and uses corridor_yaw, not turn_target_yaw).
        # That override is why the car turned the wrong way, turned very
        # late, or never turned at all and hit the front wall.
        if mode != MODE_TURN:
            steer_cmd = 0.0
            kp_wall_use = WALL_KP
            deadband_use = WALL_DEADBAND_MM
            if mode == MODE_CRUISE and clock.time() < recenter_until:
                kp_wall_use = RECENTER_WALL_KP
                deadband_use = RECENTER_DEADBAND_MM

            # heading hold (left-positive). NOTE: the P term is negative on
            # purpose -- heading_error > 0 means the car points LEFT of the
            # corridor, so it must steer RIGHT (negative) to come back.
            steer_cmd = -HEADING_KP * heading_error - YAW_DAMPING * yaw_change

            # wall-centering (CRUISE and FINAL only; needs both side walls)
            if (
                (mode == MODE_CRUISE or mode == MODE_FINAL)
                and distance_is_valid(left_mm)
                and distance_is_valid(right_mm)
            ):
                raw_wall = (left_mm - right_mm) / 2.0   # + = too close to RIGHT wall
                if abs(raw_wall) <= deadband_use:
                    raw_wall = 0.0
                filtered_wall_error += (
                    raw_wall - filtered_wall_error
                ) * WALL_FILTER_AMOUNT
                steer_cmd += kp_wall_use * filtered_wall_error

            last_steering_target = apply_steering(
                steer_cmd, last_steering_target, MAX_STEERING_DEG
            )

            # Speed: in CRUISE, a close front wall with NO opening detected
            # means a color block that has not been identified yet -- slow
            # down and keep going straight. No turn, no stop.
            if (
                mode == MODE_CRUISE
                and distance_is_valid(front_mm)
                and front_mm <= BLOCK_AHEAD_SLOWDOWN_MM
            ):
                start_drive(BLOCK_AHEAD_SPEED)
            else:
                start_drive()

        if PRINT_DEBUG:
            print(
                MODE_NAMES[mode],
                "yaw=%.0f" % yaw_deg,
                "f=%d l=%d r=%d" % (front_mm, left_mm, right_mm),
                "steer=%d" % last_steering_target,
            )

        wait(LOOP_TIME_MS)

# ------------------------------------------------------------------ entry
def main():
    print("Starting WRO obstacle course ...")

    husky = None
    connected = False
    try:
        husky = HuskyLens(HUSKY_PORT, HUSKY_BAUD, HUSKY_POWER_PIN)
        connected = husky.knock()
    except OSError as err:
        print("HuskyLens error:", err)
        connected = False

    if connected:
        print("HuskyLens connected")
        hub.light.on(Color.WHITE)
        hub.display.icon(Icon.HEART)
    else:
        print("HuskyLens NOT connected - running blind")
        hub.light.on(Color.ORANGE)
        hub.display.icon(Icon.SAD)
    wait(1000)

    try:
        drive_course(husky, connected)
    except Exception as err:
        print("Run aborted:", err)
        stop_drive()
        steer_logical(0, wait_done=False)
        hub.light.on(Color.ORANGE)
        raise

main()

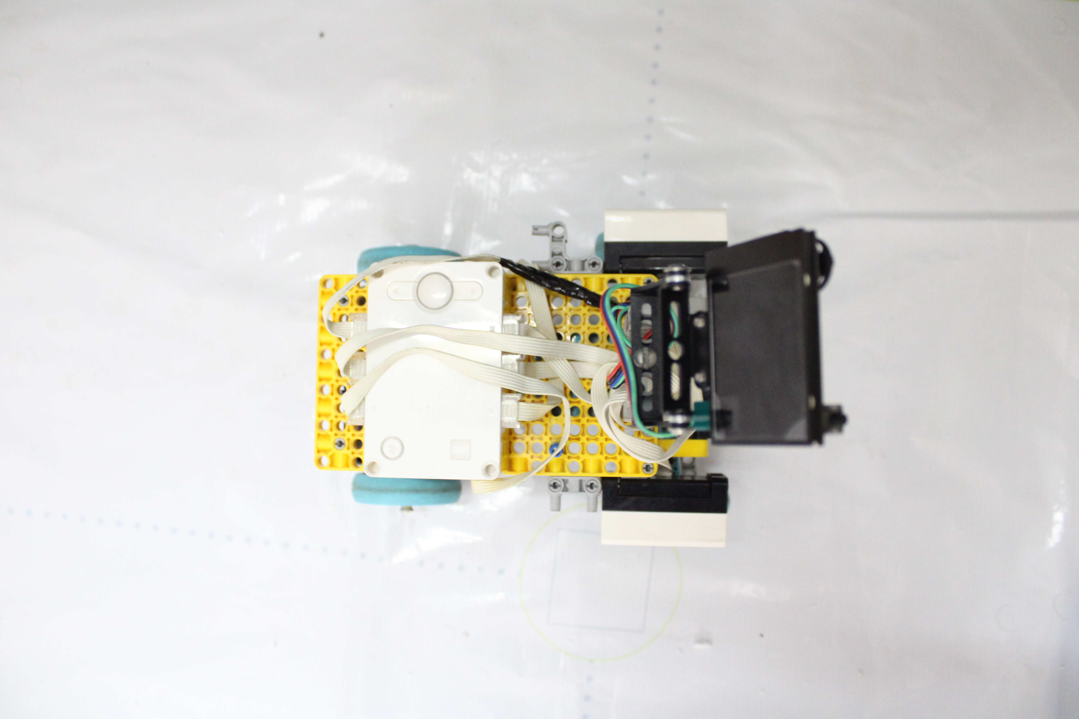
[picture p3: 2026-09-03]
Electronics/Pictures/Pixabc.com_Compressed_to_500kb_IMG_7019.jpg

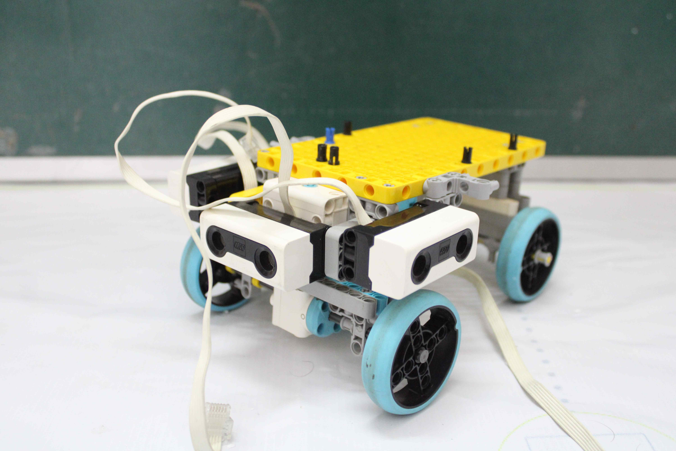
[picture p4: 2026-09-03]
Mechanical Design/Pictures/Pixabc.com_Compressed_to_500kb_IMG_7021.jpg

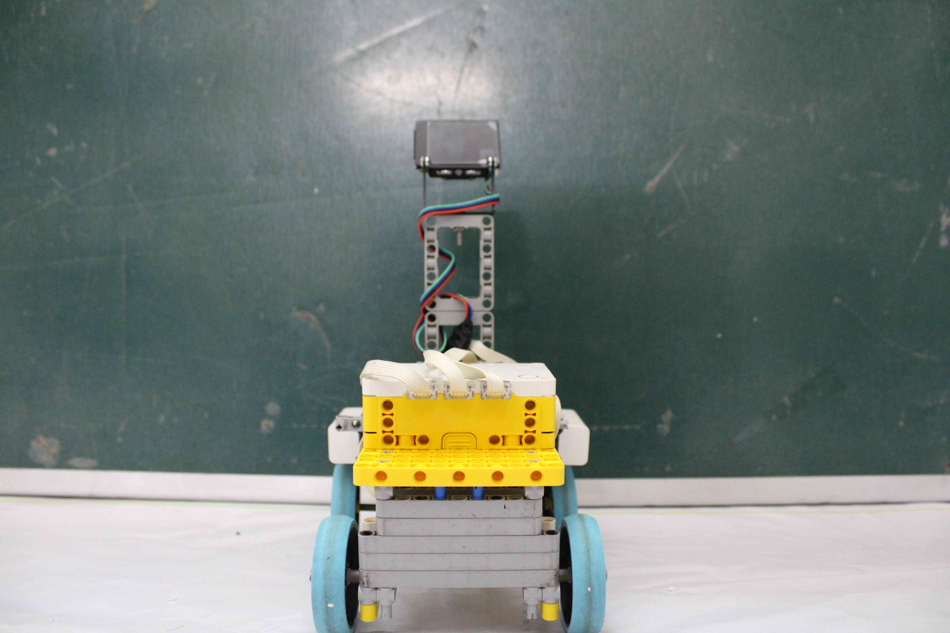
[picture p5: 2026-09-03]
Electronics/Pictures/Pixabc.com_Compressed_to_500kb_IMG_7018.jpg

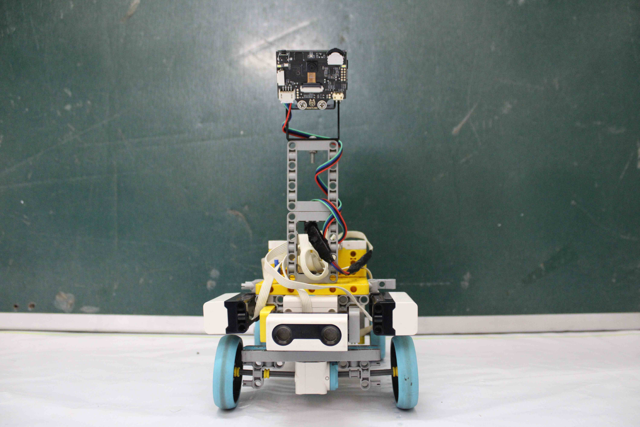
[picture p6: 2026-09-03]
Electronics/Pictures/Pixabc.com_Compressed_to_500kb_IMG_7016.jpg

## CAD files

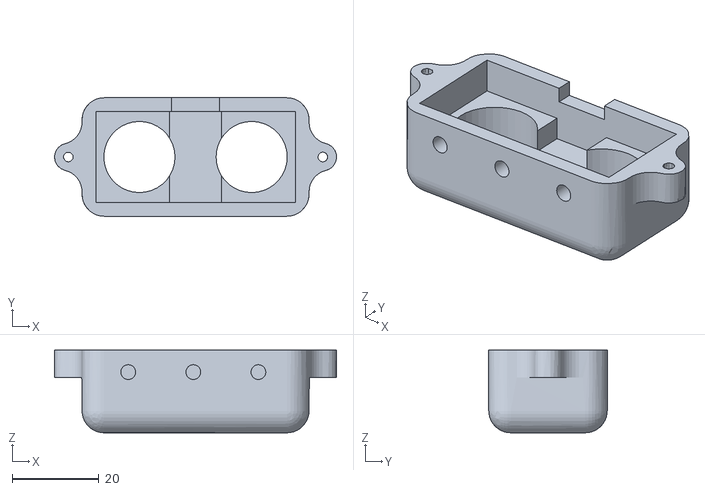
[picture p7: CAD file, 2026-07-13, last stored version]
Robot-info/3D DESIGN/Ultrasonic Sensor Housing.stl
65.0 x 27.3 x 19.1
